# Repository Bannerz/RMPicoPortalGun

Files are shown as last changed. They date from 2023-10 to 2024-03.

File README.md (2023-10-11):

# RMPicoPortalGun
Repo for my Pico portal gun from Rick and Morty

Updated to use both cores of Pico for simultaneous loops, allowing for a constant animation of the plasma tube and operation of the dial/button at the same time.

Wiring:

pim-560-01-766x511w

2820DF13-9839-4EBC-BCF0-96EE51598783_1_102_o
I used blue tack because I'm lazy. Internet says it's non conductive so should be alright.

site_img - 1
I used copper tape to create a cartridge like system so you can just slide the tray in and out for charging. Detachable wires also work (thats what I used in my first version, it was just annoying to stuff the wires in each time)

F5F65E08-65E2-43E3-8766-7F9FE2F67380_1_102_o
Inside the case, I placed copper tape, then soldered the wires onto it while it was inside. This was difficult, but doable. Good luck!

Get the micropython display driver here: https://github.com/smittytone/HT16K33-Python

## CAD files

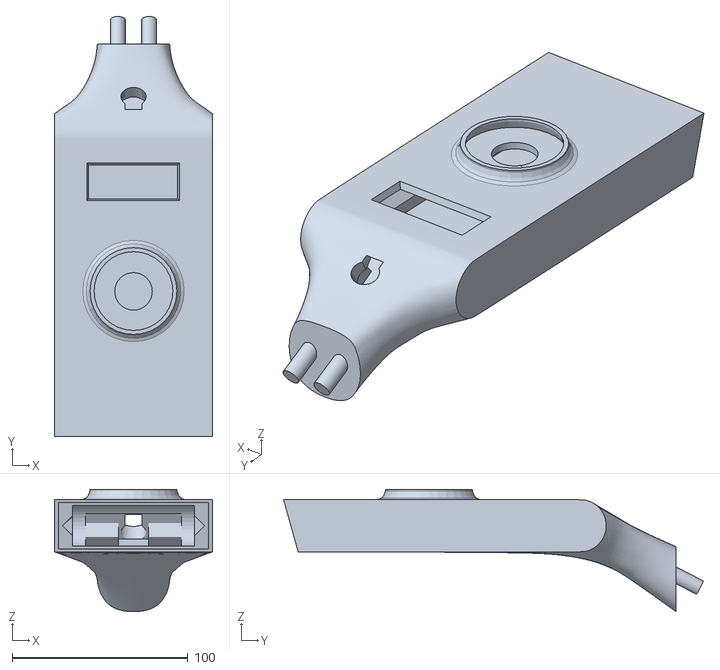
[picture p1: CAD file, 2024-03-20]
Portal Gun 2.0/main body.stl
90.0 x 239.2 x 69.6

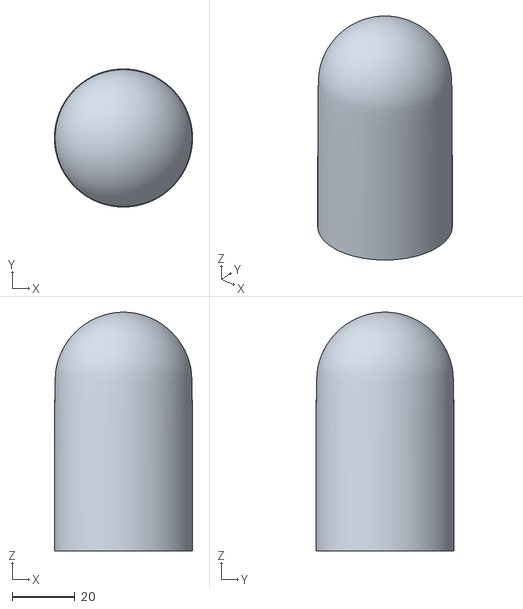
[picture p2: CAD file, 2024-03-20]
Portal Gun 2.0/tube.stl
43.9 x 43.9 x 75.9

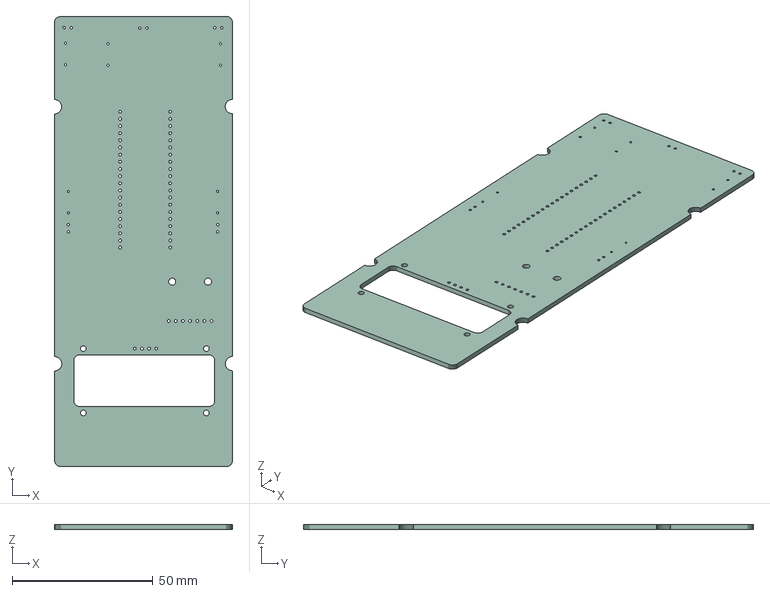
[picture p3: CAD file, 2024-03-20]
Portal Gun 2.0/KiCad/portalgun pcb.step
63.3 x 159.8 x 1.60 mm

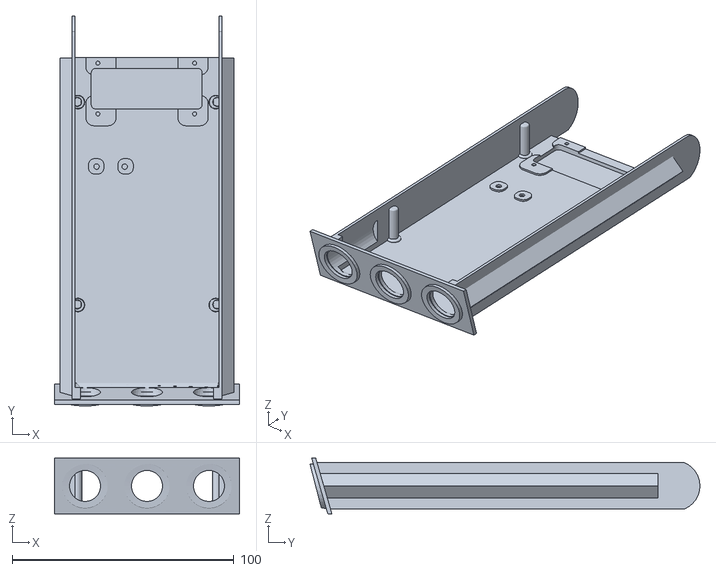
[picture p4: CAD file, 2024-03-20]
Portal Gun 2.0/traypcb.stl
83.6 x 175.9 x 25.1

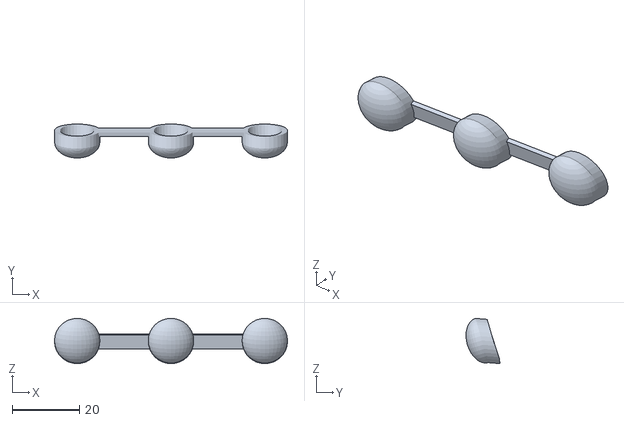
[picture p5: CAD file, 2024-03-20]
Portal Gun 2.0/led lenses.stl
69.5 x 10.1 x 13.5

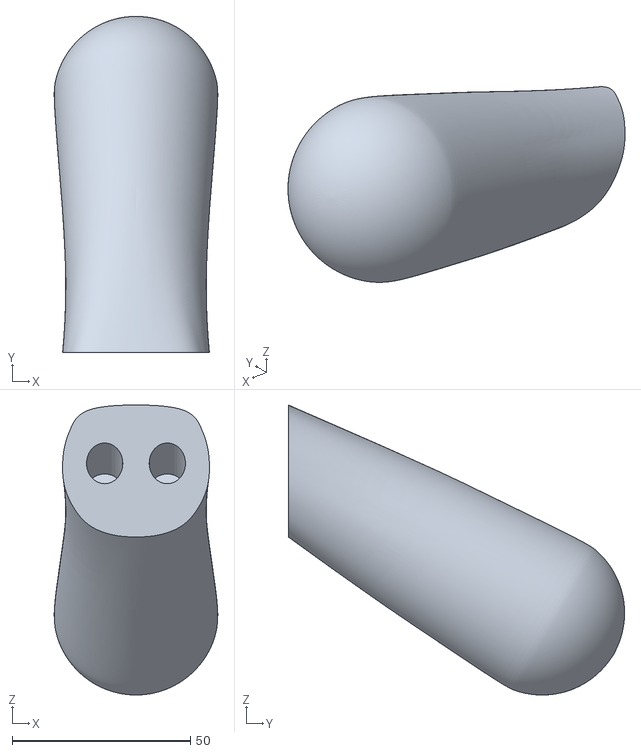
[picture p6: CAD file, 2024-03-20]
Portal Gun 2.0/handle.stl
45.9 x 94.3 x 81.3

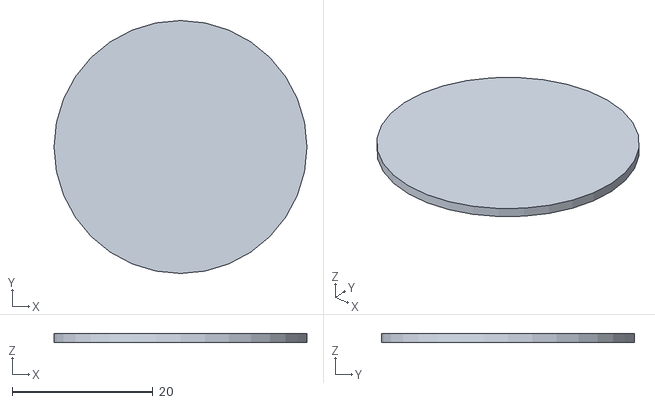
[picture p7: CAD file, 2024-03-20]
Portal Gun 2.0/diffuser.stl
35.9 x 35.9 x 1.27

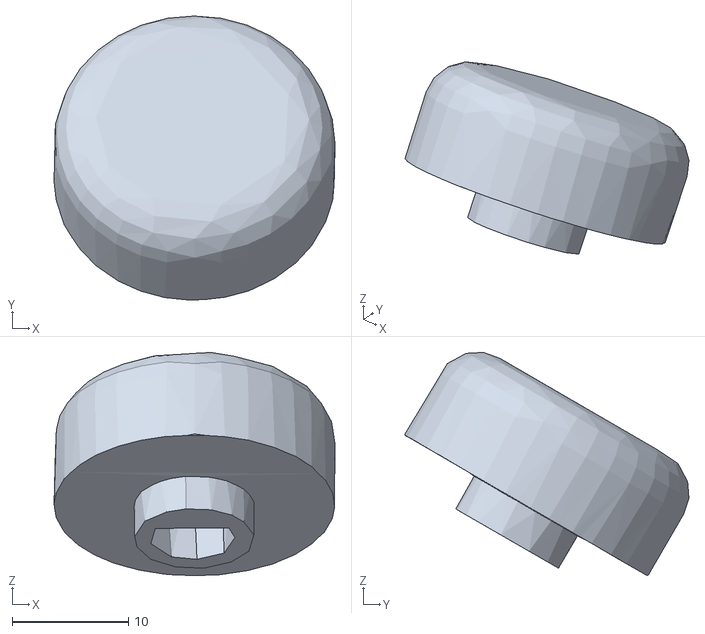
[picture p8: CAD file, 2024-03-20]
Portal Gun 2.0/knob.stl
24.1 x 24.4 x 19.2

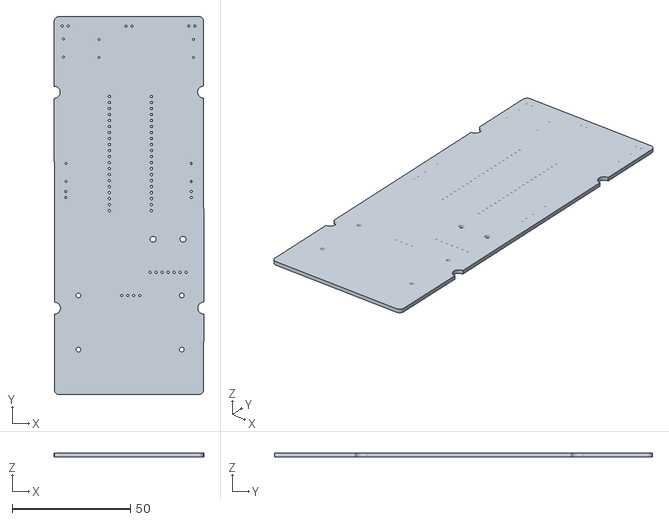
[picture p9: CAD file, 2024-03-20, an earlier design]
Portal Gun 2.0/KiCad/portalgun pcb v2.stl
63.3 x 159.8 x 1.60

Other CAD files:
Portal Gun 2.0/KiCad/portalgun pcb v3.stl
Portal Gun 2.0/KiCad/portalgun pcb.stl

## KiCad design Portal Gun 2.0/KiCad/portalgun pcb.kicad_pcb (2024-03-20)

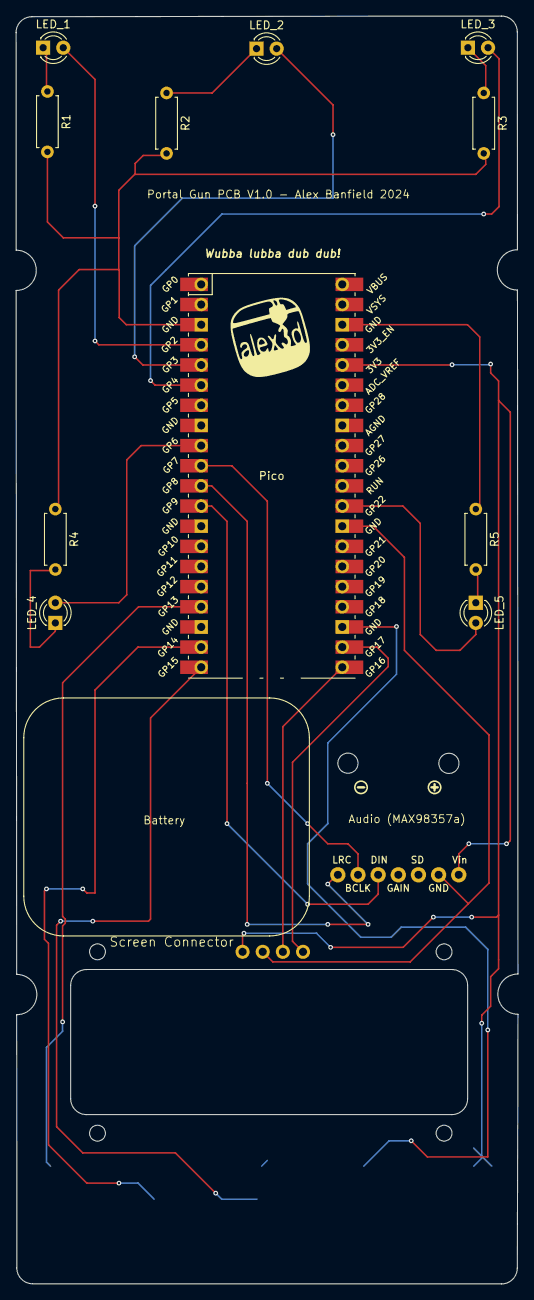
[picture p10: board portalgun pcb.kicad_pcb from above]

Board: 2 copper layers, 63.3 x 159.8 mm, 17 parts (0 on the bottom side), 11 nets.

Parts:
@HOLE1, @HOLE2, @HOLE3: (no value)
JP1: 1X07_ROUND_76
LED_1, LED_2, LED_3, LED_4, LED_5: LED_D3.0mm
Pico: RPi_Pico_SMD_TH
R1: R1; R_Axial_DIN0207_L6.3mm_D2.5mm_P7.62mm_Horizontal
R2: R2; R_Axial_DIN0207_L6.3mm_D2.5mm_P7.62mm_Horizontal
R3: R3; R_Axial_DIN0207_L6.3mm_D2.5mm_P7.62mm_Horizontal
R4: R4; R_Axial_DIN0207_L6.3mm_D2.5mm_P7.62mm_Horizontal
R5: R5; R_Axial_DIN0207_L6.3mm_D2.5mm_P7.62mm_Horizontal
minus: SYMBOL_MINUS
plus: SYMBOL_PLUS

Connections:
BLCK: JP1.6, Pico.10
DIN: JP1.5, Pico.12
LED_1: LED_1.2, Pico.4
LED_2: LED_2.2, Pico.5
LED_3: LED_3.2, Pico.6
LED_4: LED_4.2, Pico.9
LED_5: LED_5.2, Pico.29
LED_GND: LED_1.1, LED_2.1, LED_3.1, LED_4.1, LED_5.1, Pico.3, Pico.38, R1.1, R1.2, R2.1, R2.2, R3.1, R3.2, R4.1, R4.2, R5.1, R5.2
LRC: JP1.7, Pico.11
PAD_5: JP1.1, Pico.36
SCRNAUDI_GND: JP1.2, Pico.28

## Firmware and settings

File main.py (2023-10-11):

"""
    Simple code to run on a raspberry pi pico (RP2040) to make
    the portal gun project come to life I guess

    Version:    1.1
    Author:     Alex Banfield
    Copyright:  2023
"""

# IMPORTS
import math
import time
from machine import I2C, Pin, RTC
from ht16k33segment import HT16K33Segment
import _thread
import gc #garbage collect


#rotary encoder pins (pins 12, 14 & 15)
btn = Pin(12, Pin.IN, Pin.PULL_UP)
direction_pin = Pin(14, Pin.IN, Pin.PULL_UP)
step_pin = Pin(15, Pin.IN, Pin.PULL_UP)

previous_value = True
button_down = False

#character set for screen (custom glyphs)
dimensionArray = [0x00, 0x77, 0x7C, 0x39, 0x5E, 0x79, 0x71, 0x3D, 0x76, 0x30, 0x1E,
                  0x75, 0x38, 0x55, 0x37, 0x3f, 0x73, 0x67, 0x31, 0x6D, 0x78, 0x3E,
                  0x1C, 0x1D, 0x64, 0x6E, 0x5B, 0x00]


#initialise array & vars
dimNumArray = [] #empty array that will contain parted nums
dimNum = 137 #dimension number
dimCounter = 3 #dimension letter 1=a 2=b 3=c etc

#leds
#front leds
frntLed1 = machine.Pin(2, machine.Pin.OUT)
frntLed2 = machine.Pin(3, machine.Pin.OUT)
frntLed3 = machine.Pin(4, machine.Pin.OUT)
#top leds
topLed1 = machine.Pin(9, machine.Pin.OUT)
topLed2 = machine.Pin(22, machine.Pin.OUT)

#core 1 thread function (led animation, constant)
def core1_thread():
    while True:
        #turn led on
        topLed1.low()
        time.sleep(0.1)
        topLed2.high()
        time.sleep(0.1)
        topLed1.high()
        time.sleep(0.1)
        topLed2.low()
        time.sleep(0.1)
        topLed1.low()
        time.sleep(0.1)
        topLed2.high()
        time.sleep(0.1)
        topLed1.high()
        time.sleep(0.1)
        topLed2.low()
        time.sleep(0.1)
        topLed2.high()
        time.sleep(0.1)
        topLed1.low()
        time.sleep(0.1)
        topLed2.high()
        time.sleep(0.1)
        topLed1.high()
        time.sleep(0.1)
        topLed2.low()
        time.sleep(0.1)
        topLed1.low()
        time.sleep(0.1)
        topLed2.high()
        time.sleep(0.1)
        topLed1.high()
        time.sleep(0.1)
        topLed2.low()
        time.sleep(0.1)
        topLed2.high()
        
        gc.collect #collect garbage just in case

# start core 1 thread
second_thread = _thread.start_new_thread(core1_thread, ())

# start core 0 thread (encoder and front leds)
while True:
    #logic to roll over 999 to 000
    if dimNum > 999:
        dimNum = 001
        dimCounter += 1
        
    if dimNum < 001:
        dimNum = 999
        dimCounter -= 1
        
    if dimCounter > 26:
        dimCounter = 1
    
    if dimCounter < 1:
        dimCounter = 26
        
    #increment or decrement numbers on screen     
    if previous_value != step_pin.value():
        if step_pin.value() == False:
            if direction_pin.value() == False:
                dimNum -= 1
                dimNum=dimNum
                print(dimNum)
                print(dimCounter)
                
                
            else:
                dimNum += 1
                print(dimNum)
                print(dimCounter)
        previous_value = step_pin.value()
        
    
 
                    
    #make sure numbers always have 3 characters (adds leading zeros)       
    withZero = "{:03d}".format(dimNum)
    
    #can't remember exactly what this does, something like combining the letter and number and making sure it formats properly
    combinedNum = int(str(dimCounter) + str(withZero)) #total dimension number
    fixedDimNum = int(str(1) + str(withZero)) #total dimension number        
    dimNumArray = [int(x) for x in str(combinedNum)]
    fixedDimNumArray = [int(x) for x in str(fixedDimNum)]
        
    # Start screen stuff
    if __name__ == '__main__':
        
    
        i2c = I2C(0, scl=Pin(17), sda=Pin(16))  # PicoLipo i2c pins

        display = HT16K33Segment(i2c)
        display.set_brightness(20) #screen brightness control
        
        dimNumUpdate = fixedDimNumArray[1]
        dimNumUpdate1 = fixedDimNumArray[2]
        dimNumUpdate2 = fixedDimNumArray[3]

        # Write dimension to the display using the glyphs and numbers
        display.set_glyph(dimensionArray[dimCounter], 0).set_number(dimNumUpdate, 1)
        display.set_number(dimNumUpdate1, 2).set_number(dimNumUpdate2, 3)
        display.draw()
    
    # when button is clicked run this led animation     
    if btn.value() == False and not button_down:
        frntLed1.low()
        frntLed2.low()
        frntLed3.low()
        time.sleep(0.5)
        frntLed2.high()
        frntLed3.high()
        time.sleep(0.2)
        frntLed1.high()
        time.sleep(0.2)
        frntLed1.low()
        frntLed2.low()
        frntLed3.low()
        time.sleep(0.2)
        frntLed1.high()
        frntLed2.high()
        frntLed3.high()
        time.sleep(0.2)
        frntLed1.low()
        frntLed2.low()
        frntLed3.low()
        time.sleep(0.2)
        frntLed1.high()
        frntLed2.high()
        frntLed3.high()
        time.sleep(2)
        frntLed1.low()
        frntLed2.low()
        frntLed3.low()
        button_down = True
    if btn.value() == True and button_down:
        button_down = False
        
    gc.collect #collect garbage just in case
    
        
        


        

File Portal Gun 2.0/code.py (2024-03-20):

#Updated Circuitpython code for Raspberry Pi Pico (RP2040)
#to make the Portal Gun project REALLY come to life

#Version: 2.3
#Author: Alex Banfield
#Copyright: 2024

#imports
import board
import digitalio
import time
import array
import math
import audiocore
import audiobusio
import audiomp3
import rotaryio
from adafruit_ht16k33.segments import Seg7x4
import busio
import random


#timings for top LEDs
BLINK_LIST = [
    {
        "ON": random.uniform(0.05, 0.2),
        "OFF": random.uniform(0.05, 0.2),
        "PREV_TIME": -1,
        "PIN": board.GP6,
    },
    {
        "ON": random.uniform(0.05, 0.2),
        "OFF": random.uniform(0.05, 0.2),
        "PREV_TIME": -1,
        "PIN": board.GP22,
    }
]

#timings for front LEDs
FRONT_LIST = [
    {
        "ON": random.uniform(0.05, 0.2),
        "OFF": random.uniform(0.05, 0.2),
        "PREV_TIME": -1,
        "PIN": board.GP2,
    },
    {
        "ON": random.uniform(0.05, 0.2),
        "OFF": random.uniform(0.05, 0.2),
        "PREV_TIME": -1,
        "PIN": board.GP3,
    },
    {
        "ON": random.uniform(0.05, 0.2),
        "OFF": random.uniform(0.05, 0.2),
        "PREV_TIME": -1,
        "PIN": board.GP4,
    }
]

#initialise both lists of LEDs
for led in BLINK_LIST:
    led["PIN"] = digitalio.DigitalInOut(led["PIN"])
    led["PIN"].direction = digitalio.Direction.OUTPUT
    
for led in FRONT_LIST:
    led["PIN"] = digitalio.DigitalInOut(led["PIN"])
    led["PIN"].direction = digitalio.Direction.OUTPUT

#initialise display on i2c
i2c = busio.I2C(board.GP17, board.GP16)
display = Seg7x4(i2c)

#initialise i2s audio
audio = audiobusio.I2SOut(board.GP7, board.GP8, board.GP9)
#get mp3 sound (must be in root dir on pico)
mp3 = audiomp3.MP3Decoder(open("sound1.mp3", "rb"))
#initialise encoder
encoder = rotaryio.IncrementalEncoder(board.GP15, board.GP14)
encoder.position = 137  #set the initial position to 137
last_position = encoder.position
letter_index = 2  #index of the alphabet letter 'C'

#update display with initial values
display[0] = 'C'
display[1] = '1'
display[2] = '3'
display[3] = '7'

#initialise button
button = digitalio.DigitalInOut(board.GP13)
button.direction = digitalio.Direction.INPUT
button.pull = digitalio.Pull.UP

button_state = None

#main loop
while True:
    #get time
    now = time.monotonic()
    #button logic    
    if not button.value and button_state is None:
        button_state = "pressed"
    if button.value and button_state == "pressed":
        print("Button pressed.")
        #play the sound
        audio.play(mp3)
        while audio.playing:
            #while playing the sound do the animations
            now = time.monotonic()
            for led in BLINK_LIST:
                if led["PIN"].value is False:
                    if now >= led["PREV_TIME"] + led["OFF"]:
                        led["PREV_TIME"] = now
                        led["PIN"].value = True
                if led["PIN"].value is True:
                    if now >= led["PREV_TIME"] + led["ON"]:
                        led["PREV_TIME"] = now
                        led["PIN"].value = False
            for led in FRONT_LIST:
                if led["PIN"].value is False:
                    if now >= led["PREV_TIME"] + led["OFF"]:
                        led["PREV_TIME"] = now
                        led["PIN"].value = True
                if led["PIN"].value is True:
                    if now >= led["PREV_TIME"] + led["ON"]:
                        led["PREV_TIME"] = now
                        led["PIN"].value = False
        #set the front leds to off when sound ends
        for led in FRONT_LIST:
            led["PIN"].value = False
        button_state = None
    #do the top led animation
    for led in BLINK_LIST:
        if led["PIN"].value is False:
            if now >= led["PREV_TIME"] + led["OFF"]:
                led["PREV_TIME"] = now
                led["PIN"].value = True
        if led["PIN"].value is True:
            if now >= led["PREV_TIME"] + led["ON"]:
                led["PREV_TIME"] = now
                led["PIN"].value = False
 
     #read the current position of the rotary encoder
    position = encoder.position
    
    #check if the position has changed since the last iteration
    if position != last_position:
        #limit position to 0-999 range
        position %= 1000
        
        #check for rollover from 000 to 999
        if last_position == 0 and position == 999:
            #decrement letter index
            letter_index = (letter_index - 1) % 26
            
            #update the displayed characters on the 7-segment display
            letter = chr(ord('A') + letter_index)
            display[0] = letter
            display[1] = str(position // 100)
            display[2] = str((position // 10) % 10)
            display[3] = str(position % 10)
            
            #update the last position
            last_position = position
            continue  #skip further processing for this iteration
        
        #check for rollover from 999 to 000
        elif last_position == 999 and position == 0:
            #increment letter index
            letter_index = (letter_index + 1) % 26
            
            #update the displayed characters on the 7-segment display
            letter = chr(ord('A') + letter_index)
            display[0] = letter
            display[1] = str(position // 100)
            display[2] = str((position // 10) % 10)
            display[3] = str(position % 10)
            
            #update the last position
            last_position = position
            continue  # Skip further processing for this iteration
        
        #update the displayed characters on the 7-segment display
        letter = chr(ord('A') + letter_index)
        display[0] = letter
        display[1] = str(position // 100)
        display[2] = str((position // 10) % 10)
        display[3] = str(position % 10)
        
        #update the last position
        last_position = position

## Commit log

2023-10-11 Update main.py
    Added multithreading so animation can play on top LEDs while still allowing dial to be usable.
    Changed the front LEDs to be off until button clicked and plays a little light show before turning off again
2024-03-20 Portal Gun Version 2
    This is the new version built in Circuitpython to take advantage of Adafruits amazing libraries. This version adds sound and is written for the circuit board I designed (also included)
    [diffuser.stl, handle.stl, knob.stl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]
